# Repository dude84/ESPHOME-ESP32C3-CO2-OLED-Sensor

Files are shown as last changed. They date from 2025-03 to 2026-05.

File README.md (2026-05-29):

# ESPHOME ESP32-C3 Super Mini CO2 OLED Sensor

This project is designed to monitor indoor air quality by measuring CO₂ levels using a Sensirion [SDC41](https://www.sensirion.com/en/environmental-sensors/industrial-co2-sensor-sdc41/) sensor. The system is built on an [ESP32-C3 Super Mini](https://www.espboards.dev/esp32/esp32-c3-super-mini/) board running ESPHome firmware. Sensor data (CO₂, temperature, and humidity) is displayed in real time on an [OLED 128×64 display](https://www.aliexpress.com/item/32896971385.html) that shows a top-line reading, a Wi‑Fi connectivity icon, a bar indicator for CO₂ levels, a status word, and a small tag in the lower left corner.

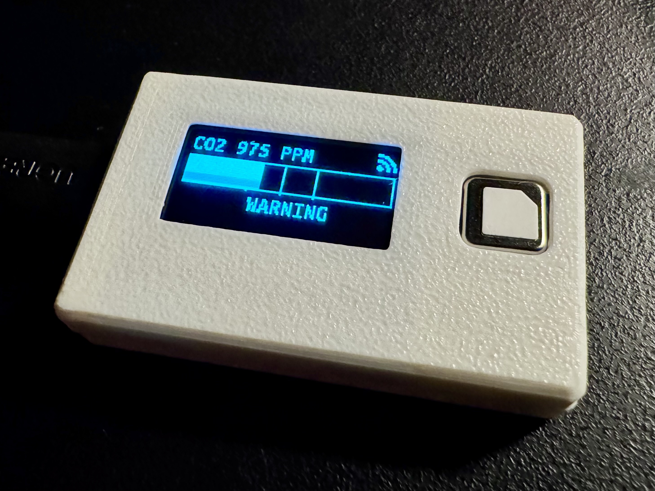
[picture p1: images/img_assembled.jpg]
Assembled Project


## Features

- **CO₂, Temperature, and Humidity Monitoring:**  
  Uses the Sensirion SDC41 sensor to accurately measure indoor air quality.
  
- **OLED Display:**  
  Displays:
  - The current CO₂ value in large text at the top.
  - A 12×12 Wi‑Fi icon in the top right indicating network connectivity.
  - A bar indicator representing CO₂ levels relative to configurable thresholds.
  - A status word ("SAFE", "WARNING", "DANGER", "CRITICAL") based on sensor readings.
  - A small tag (defined via configuration substitutions) in the bottom left corner.

- **Configurable Thresholds and Home Assistant Integration:**  
  Thresholds for safe, warning, dangerous, and critical levels can be adjusted via Home Assistant. Other settings (such as brightness) may also be updated remotely.

- **3D Printed Case:**  
  The project includes a custom 3D printed case. STEP files for the case are available in the repository at:  
  `3d_models/ESPHOME-ESP32C3-CO2-OLED-Sensor_Case_Top_Bottom.step`

## Hardware Connections
  The idea behind this project was that anyone can put this together with basic soldering and 3d printing skills - there is no PCB there, only isolated fly-wires, as the wiring requires linking:
  - I2C interface (SDA Software I2C uses GPIO02 on ESP32, SCL Software I2C uses GPIO03 on ESP32)
  - 3.3v
  - GND

### Wiring Schema

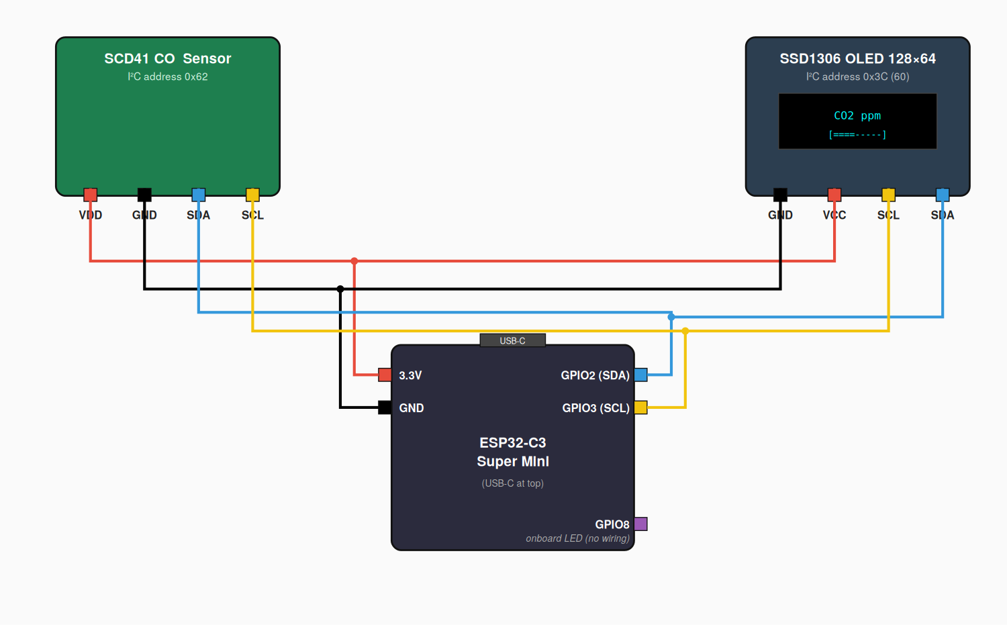
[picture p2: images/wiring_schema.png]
Wiring Schema


All three modules share a single I²C bus plus 3.3V and GND. Wire colors above are illustrative — match by signal, not by the color of the wire you actually use.

> **Note:** The pin *order* on the SSD1306 OLED varies by vendor (some are `GND/VCC/SCL/SDA`, others `VCC/GND/SCL/SDA`). Always go by the silkscreen labels on your actual board. Both the SCD41 and the OLED have onboard I²C pull-ups, so no external resistors are needed.

### Pin Mapping

- **ESP32-C3 Super Mini Board:**  
  - **I2C Bus:**  
    - **SDA:** Connected to GPIO2  
    - **SCL:** Connected to GPIO3
  - **OLED Display:** Connected via I2C (address 60)
  - **SDC41 Sensor:** Connected via I2C (address 0x62)
  - **LED Output:** Connected to GPIO8 for status indication

> **Note:** GPIO2 is a boot strapping pin on the ESP32-C3. Although strapping pins should generally be used cautiously, GPIO2 has been tested in this design as the I²C SDA line and operates reliably with the SCD41 sensor. This choice intentionally preserves other GPIOs for future expansion, while avoiding GPIO8, which is typically shared with the onboard status LED.

- **Sensirion SDC41 CO₂ Sensor:**  
  A high-precision sensor for CO₂, temperature, and humidity that communicates over I2C.

- **OLED 128×64 SSD1306 Display:**  
  A common display module that uses the SSD1306 driver over I2C.

## Configuration Secrets and Tag

Before deploying the firmware, configure the following secrets in your ESPHome secrets file:

- **API Password:**  
  `api_password` – Used for API encryption.

- **OTA Password:**  
  `ota_password` – Required for over-the-air firmware updates.

- **WiFi Credentials:**  
  - `wifi_ssid` – Your WiFi network name.
  - `wifi_password` – Your WiFi network password.
  - `wifi_fallback_password` – Device fallback WiFi password.

Additionally, set the following substitution:

- **Tag:**  
  `tag` – For example, set to `pr` (or your preferred identifier). This is used in the device name and description:
  - `name: sg-co2-v2-${tag}`
  - `device_description: "SG SDC41 CO2 Sensor V2 ${tag}"`

## Useful Links

- [Sensirion SDC41 CO₂ Sensor](https://www.sensirion.com/en/environmental-sensors/industrial-co2-sensor-sdc41/)
- [ESP32-C3 Super Mini Board](https://www.espboards.dev/esp32/esp32-c3-super-mini/)
- [SSD1306 OLED Display Module](https://www.aliexpress.com/item/32896971385.html)

## Project Photos

### Open Case
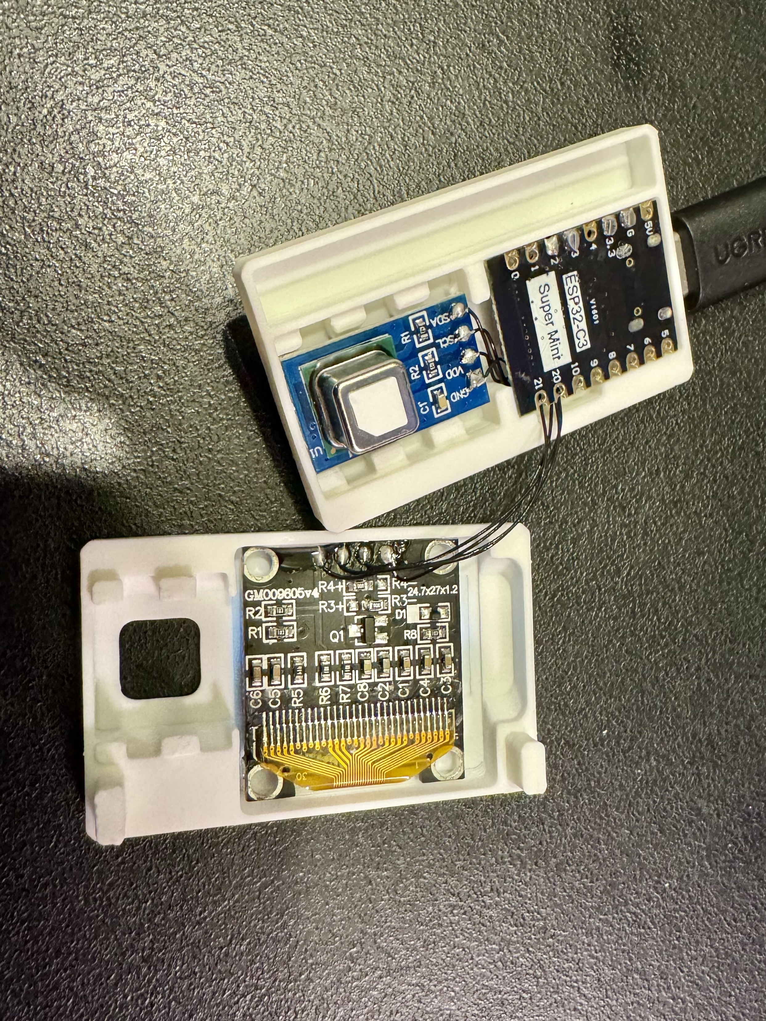
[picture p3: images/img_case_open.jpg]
Open Case


### No Case
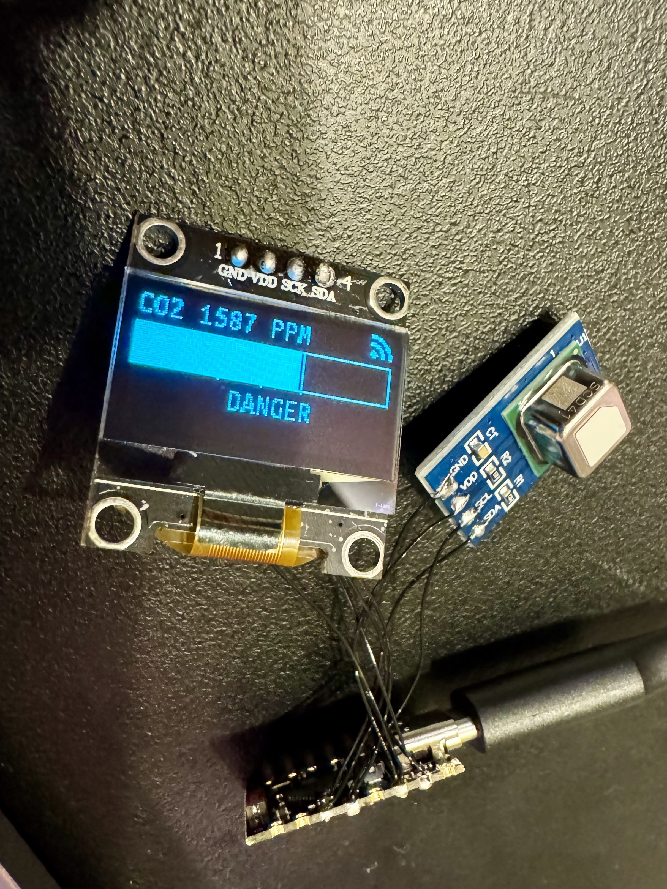
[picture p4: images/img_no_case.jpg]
No Case


## License

This project is licensed under the GNU General Public License v3.0. See the [LICENSE](LICENSE) file for details.

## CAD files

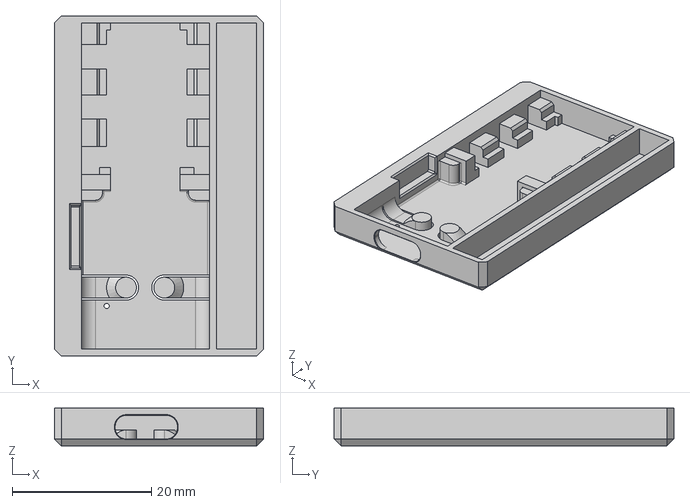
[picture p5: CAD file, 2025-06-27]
3d_models/ESPHOME-ESP32C3-CO2-OLED-Sensor_Case_Bottom.step
30.1 x 48.9 x 5.45 mm

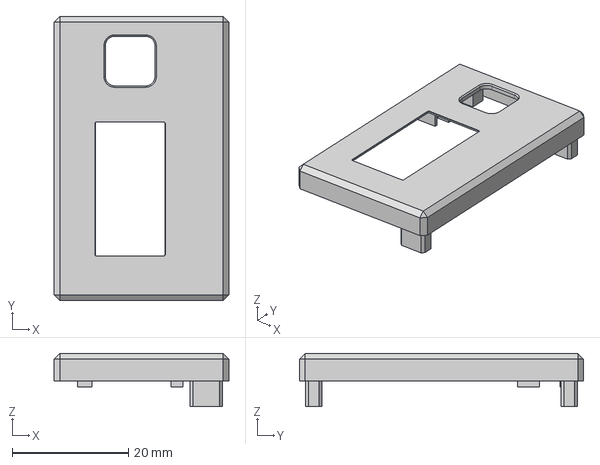
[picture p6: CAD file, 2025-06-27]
3d_models/ESPHOME-ESP32C3-CO2-OLED-Sensor_Case_Top.step
30.1 x 48.9 x 9.17 mm

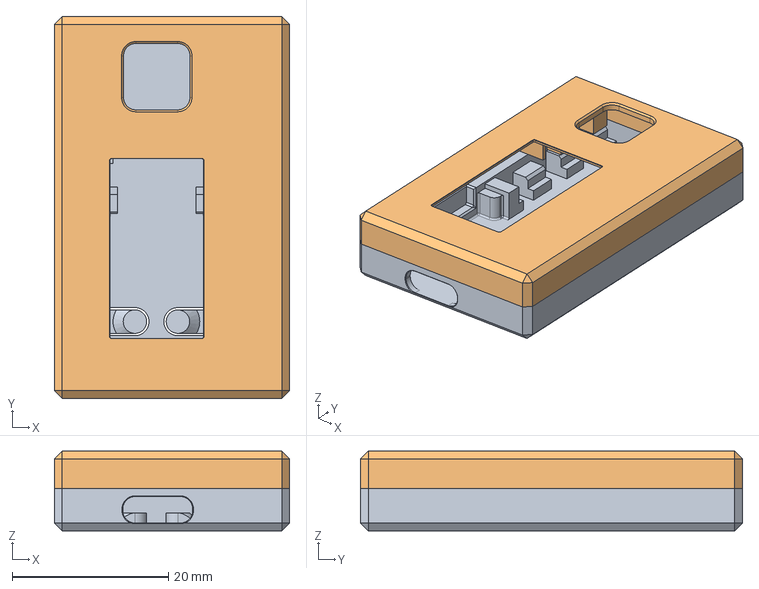
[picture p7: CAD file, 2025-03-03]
3d_models/ESPHOME-ESP32C3-CO2-OLED-Sensor_Case_Top_Bottom.step
30.1 x 48.9 x 10.2 mm

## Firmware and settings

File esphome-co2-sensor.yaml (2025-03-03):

substitutions:
  tag: office
  name: esphome-co2-sensor-${tag}
  device_description: "ESPHOME CO2 Sensor (${tag})"

esphome:
  name: ${name}
  comment: ${device_description}
  friendly_name: esphome-co2-sensor-${tag}

esp32:
  board: esp32-c3-devkitm-1
  framework:
    type: arduino

# Enable logging
logger:

api:
  reboot_timeout: 0s
  encryption:
    key: !secret api_password

ota:
  - platform: esphome
    password: !secret ota_password

wifi:
  ssid: !secret wifi_ssid
  password: !secret wifi_password
  fast_connect: true

  # Enable fallback hotspot (captive portal) in case wifi connection fails
  ap:
    ssid: "esphome-co2-sensor-${tag} Fallback Hotspot"
    password: !secret wifi_fallback_password

captive_portal:

web_server:
  port: 80
  version: 3

i2c:
  sda: GPIO2
  scl: GPIO3
  scan: true
  id: i2c_bus

# i2c device at address 0x3C //OLED 128x64
# i2c device at address 0x62 //SDC41

sensor:
  - platform: scd4x
    id: co2_sensor
    i2c_id: i2c_bus
    address: 0x62
    co2:
      name: "CO2"
      id: co2
    temperature:
      name: "Temperature"
      id: co2_temperature
    humidity:
      name: "Humidity"
      id: co2_humidity
    update_interval: 1s

light:
  - platform: binary
    name: "LED"
    output: led_output

output:
  - id: led_output
    platform: gpio
    inverted: True
    pin: GPIO8

# Expose threshold values as numbers so they appear in Home Assistant.
number:
  - platform: template
    name: "Safe Threshold"
    id: safe_threshold
    optimistic: true
    restore_value: true
    initial_value: 800
    min_value: 0
    max_value: 5000
    step: 1
  - platform: template
    name: "Warning Threshold"
    id: warning_threshold
    optimistic: true
    restore_value: true
    initial_value: 1200
    min_value: 0
    max_value: 5000
    step: 1
  - platform: template
    name: "Dangerous Threshold"
    id: dangerous_threshold
    optimistic: true
    restore_value: true
    initial_value: 1600
    min_value: 0
    max_value: 5000
    step: 1
  - platform: template
    name: "Critical Threshold"
    id: critical_threshold
    optimistic: true
    restore_value: true
    initial_value: 2500
    min_value: 0
    max_value: 5000
    step: 1

# If you want the status names to be configurable, you can use globals or text sensors.
globals:
  - id: safe_name
    type: std::string
    restore_value: no
    initial_value: '"SAFE"'
  - id: warning_name
    type: std::string
    restore_value: no
    initial_value: '"WARNING"'
  - id: dangerous_name
    type: std::string
    restore_value: no
    initial_value: '"DANGER"'
  - id: critical_name
    type: std::string
    restore_value: no
    initial_value: '"CRITICAL"'

# Use a custom TTF font from the web.
font:
  - file: "https://github.com/canonical/Ubuntu-Sans-Mono-fonts/raw/refs/heads/main/fonts/ttf/UbuntuSansMono-Medium.ttf"
    id: font_large
    size: 12
  - file: "https://github.com/canonical/Ubuntu-Sans-Mono-fonts/raw/refs/heads/main/fonts/ttf/UbuntuSansMono-Medium.ttf"
    id: font_small
    size: 8

display:
  - platform: ssd1306_i2c
    id: oled_display
    model: "SSD1306 128x64"
    address: 60
    update_interval: 1s
    brightness: 1.0
    lambda: |-
      // ---- Top Status Line (0-12px): Only CO2 reading using larger text ----
      {
        char buf[64];
        sprintf(buf, "CO2 %d PPM", (int) id(co2).state);
        it.print(0, 0, id(font_large), buf);
      }

      // ---- WiFi Icon (12x12) at the top right ----
      if (WiFi.isConnected()) {
        // Draw the WiFi icon bitmap at position (116, 0) (12x12 pixels).
        static const uint8_t wifi_icon_bitmap[] = {
          0xe0, 0x00,
          0xfc, 0x00,
          0x0e, 0x00,
          0x03, 0x00,
          0xe1, 0x80,
          0xf8, 0xc0,
          0x1c, 0xe0,
          0x06, 0x60,
          0x46, 0x20,
          0xe3, 0x30,
          0xf3, 0x30,
          0x63, 0x30
        };
        for (int row = 0; row < 12; row++) {
          for (int col = 0; col < 12; col++) {
            int byte_index = row * 2 + (col / 8);
            int bit = 7 - (col % 8);
            if (wifi_icon_bitmap[byte_index] & (1 << bit)) {
              it.draw_pixel_at(116 + col, row, COLOR_ON);
            }
          }
        }
      } else {
        // If WiFi is not connected, display a simple "X" at the icon location.
        it.print(116, 0, id(font_large), "X");
      }

      // ---- Bar Indicator for CO2 level ----
      // Reserve area starting at y = 16 for the bar.
      int bar_x = 0;
      int bar_y = 16;
      int bar_width = 128;
      int bar_height = 20;
      // Draw the outline of the bar.
      it.rectangle(bar_x, bar_y, bar_width, bar_height, COLOR_ON);

      // Retrieve thresholds from the number components.
      int safe_val = (int) id(safe_threshold).state;
      int warn_val = (int) id(warning_threshold).state;
      int danger_val = (int) id(dangerous_threshold).state;
      int crit_val = (int) id(critical_threshold).state;
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

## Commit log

2025-03-03 Create esphome-co2-sensor.yaml
    initial commit
2025-03-03 Add files via upload
    STEP file
    [ESPHOME-ESP32C3-CO2-OLED-Sensor_Case_Top_Bottom.step]
2025-03-03 images and models
    [ESPHOME-ESP32C3-CO2-OLED-Sensor_Case_Top_Bottom.step]
2025-06-27 Split case into two files
    [ESPHOME-ESP32C3-CO2-OLED-Sensor_Case_Bottom.step, ESPHOME-ESP32C3-CO2-OLED-Sensor_Case_Top.step]
2026-05-28 Add wiring schema to Hardware Connections section (closes #2)
2026-05-29 Update README with GPIO2 usage note
    Added note about GPIO2 usage and its reliability with SCD41 sensor.
